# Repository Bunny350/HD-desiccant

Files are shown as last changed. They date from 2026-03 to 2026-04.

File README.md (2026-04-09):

# HD desiccant holder

*The best calibration model since everything else.*

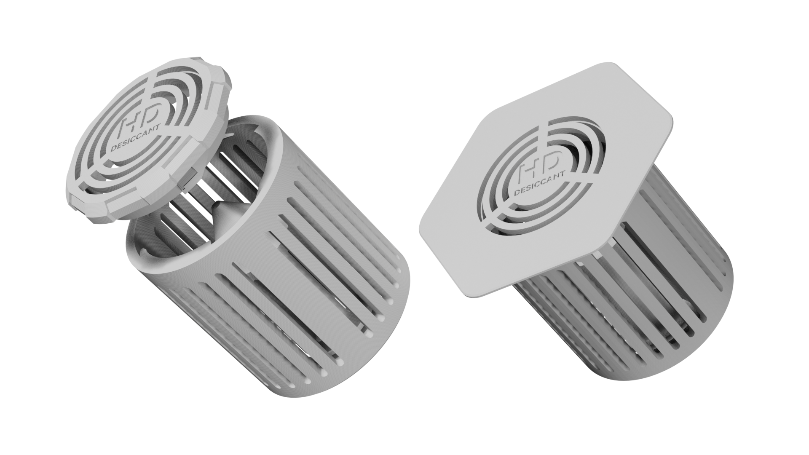
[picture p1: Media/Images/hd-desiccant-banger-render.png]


This desiccant holder / container is called HD desiccant holder because it holds any type of desiccant *in diameters that are within 3mm to 5mm*. It has 2mm wide grills that improves drying performance when being dried by normal filament dryers. Becuase of this, salvaging desiccant bags for this is not recommended as they contain pellets that are smaller than the holder's grill.

It is also a great printer / filament torture test as it tests every aspect of the printer's tolerances and mostly filament retraction.

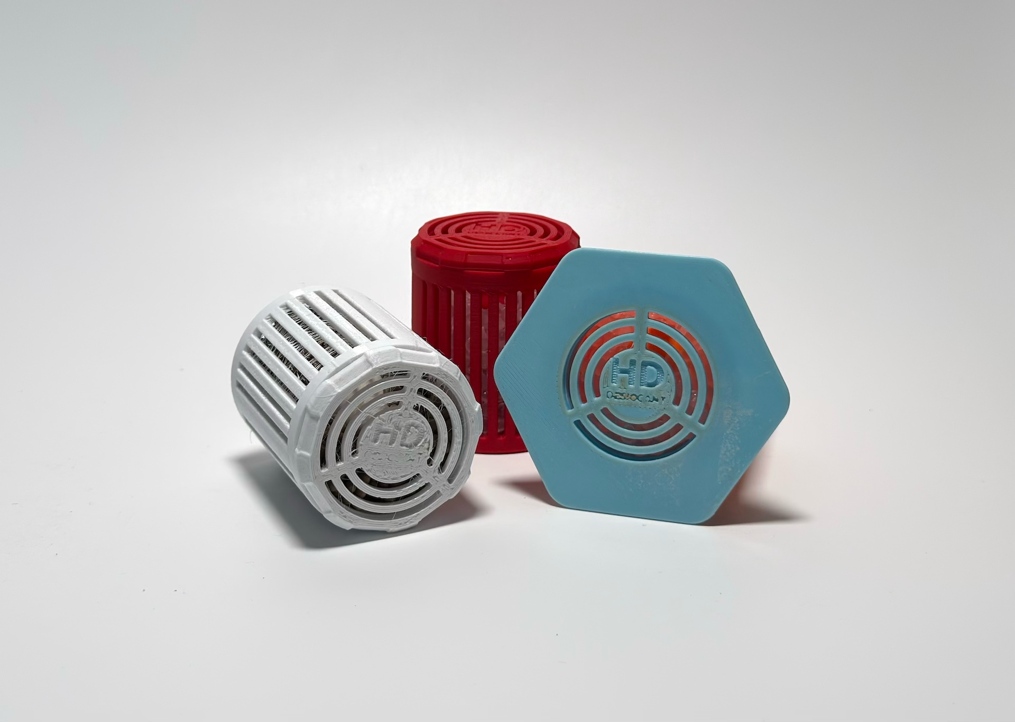
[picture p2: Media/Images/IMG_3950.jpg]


Since I don't like other desiccants for their strict tolerances **(after printing)** and the outcome of it's smaller pellet compatibility with poorer drying performance, I decided to make it myself. Heavily relied on thin extrude feature that introduced four years ago, and simple locking mechanism.

[Snappy sounds demo (Instagram)](https://www.instagram.com/reel/DVqocWHkwL2/)

## Recommended materials
* ABS
* ASA

* PET-G
    * May be minorly distortied by heat under high heat mode. However this does not affect the performance.
    
* PC
    * It requires excessive force to lock initially, at least V0.2378 and Bambu PC.
    
* FDM / FFF PA
    * It may lead to worse tolerances. It's probably one of the materials that are hard to tune.

* Just don't make it via PLA or PVB as these will have insanely obvious problems, unless it says it can tolerate high temperatures (something like Polymaker HT-PLA).

Any other materials, such as SLA photoplastics are also welcome, so we can torture more types of printers.

## Requirements
* The printer and the material must handle 0.2mm tolerances.
    * If the printer cannot handle 0.2mm tolerances, including but not limited to the lid not slotting into the bottom holder, then try drying the material first, before adjusting on the slicer- and printer-side.
    
* Easily-configurable parametric model requires either Fusion or online connection and MakerWorld.
* [Starter packs (drag-drop & YOLO print) is exclusive to MakerWorld.](https://makerworld.com/models/2565724-hd-desiccant-holder#profileId-2827543)

## Assembly



* Carefully fill the desiccant holder (desiccant_bottom_casing) using the desiccant of your choice.

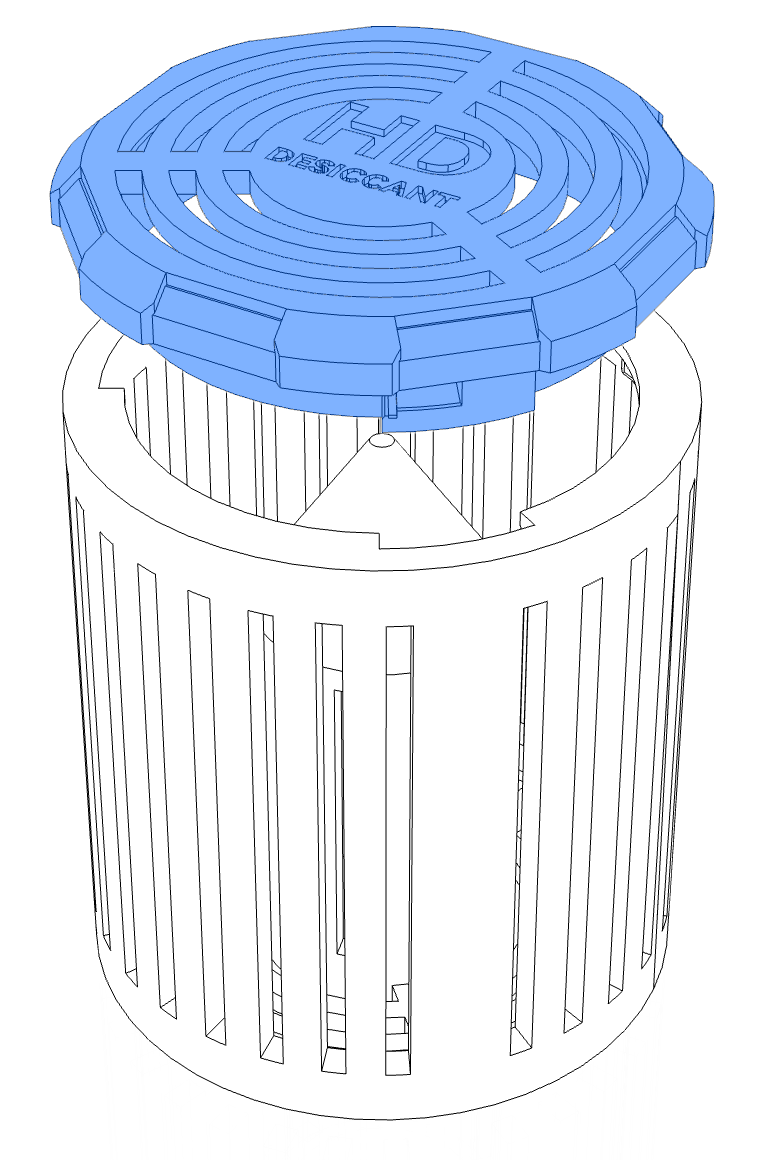
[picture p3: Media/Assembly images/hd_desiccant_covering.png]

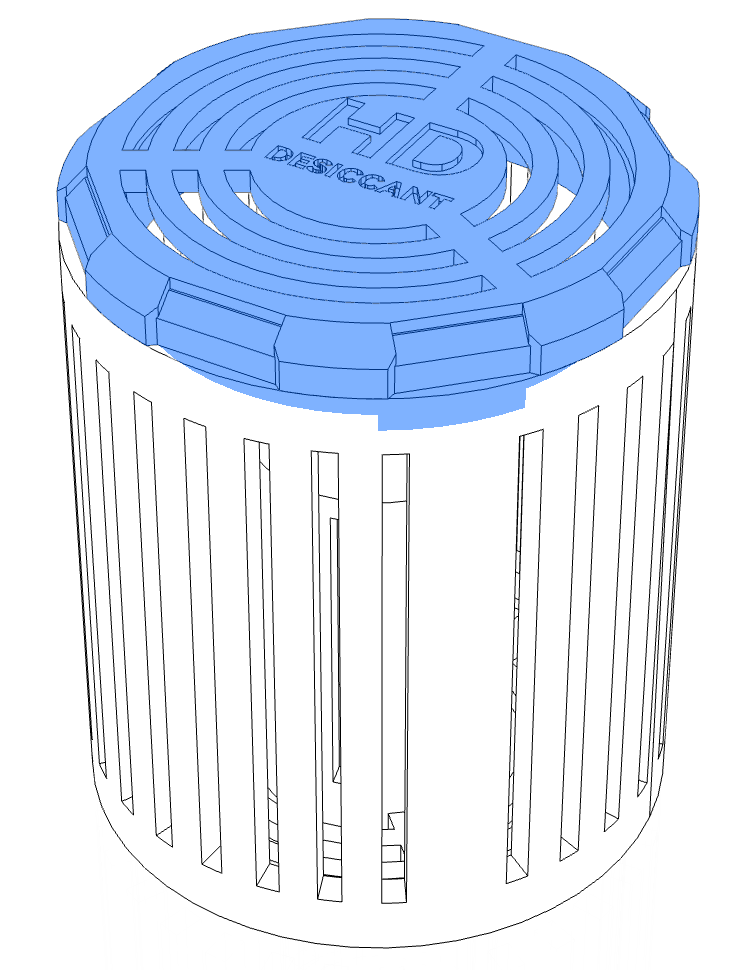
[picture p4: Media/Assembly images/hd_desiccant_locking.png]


*Note: these images are from the early prototype.*

* Close the desiccant holder with the lid (desiccant_top_lid). Turn the lid clockwise to lock it. It may make a click.

## Disassembly
If HD desiccant did not dry properly, or for whatever reason, you can easily disassemble it, as easy as assembling it.




*Note: these images are from the early prototype.*

* Turn the lid counter-clockwise, and then the lid will extend on its own. You can carefully pull the lid if it can't be extended on its own.
* The desiccant can be removed and rejuvenated without the holder.

## Drying
Desiccant in HD desiccant holder can be rejuvenated / dried within minimum setting of medium heat (around 60˚C) and 6 hours.

## Intense R&D
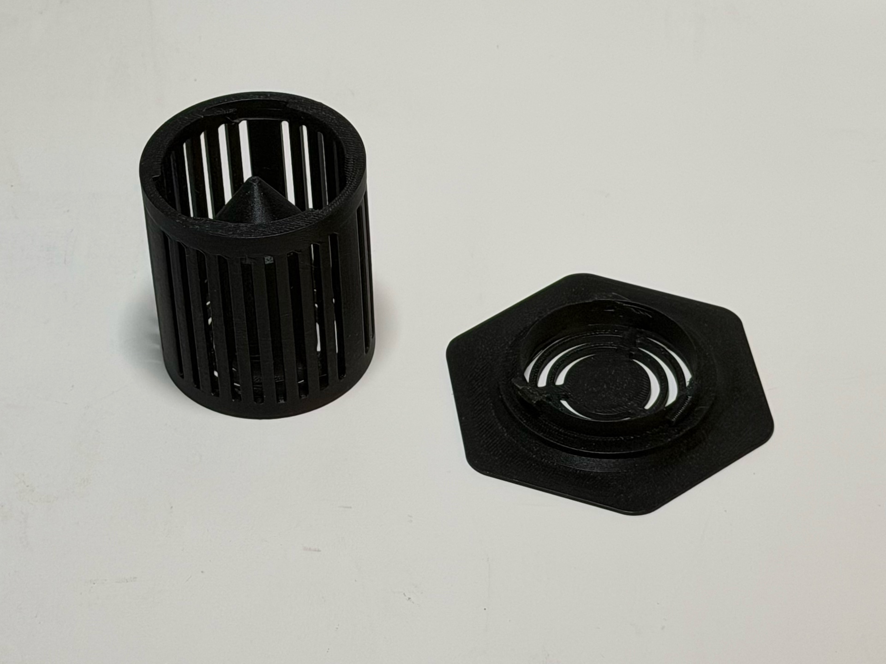
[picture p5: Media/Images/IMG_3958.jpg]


Before this model is being published to MakerWorld, I've managed to destroy multiples of these model just via hand and dropping. Apparently the design with sharp vertical corners are not suitable for typical FDM / FFF printing.

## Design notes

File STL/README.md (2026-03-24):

This file only contains the default configuration of HD desiccant. It has the height of 60mm. To change the desiccant container / holder's height, you may use its CAD file and adjust the height. You can also [visit it in MakerWorld](https://makerworld.com/models/2565724-hd-desiccant-holder#profileId-2827543) to adjust the height to your filament's thickness online.

You can choose either one with the normal top lid or the foolproof top lid with the hexagonal top brim.

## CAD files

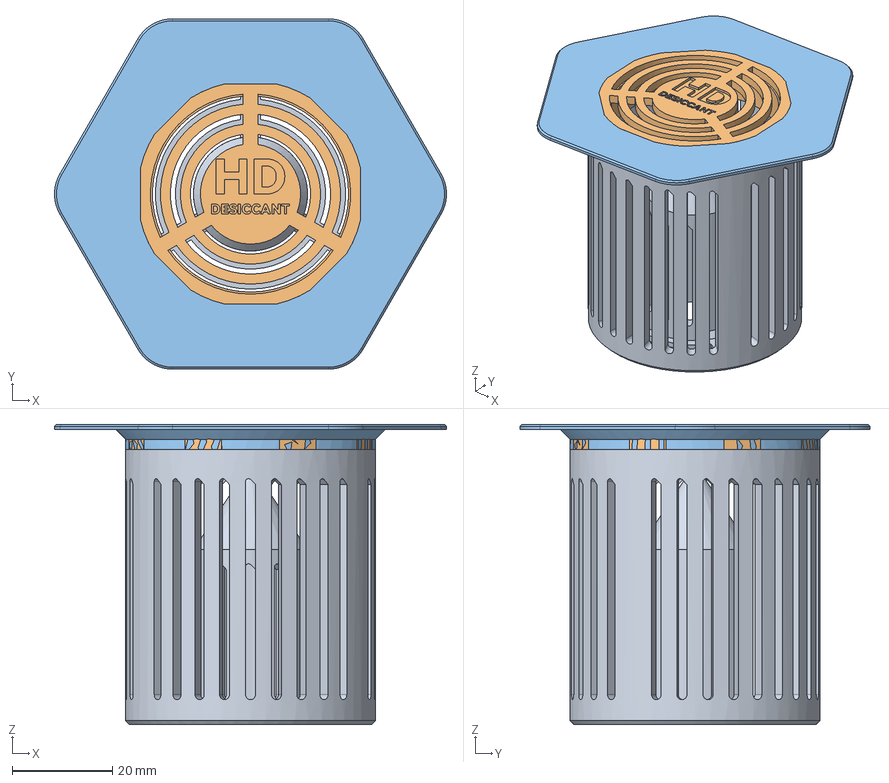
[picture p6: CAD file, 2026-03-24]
CAD/HD desiccant case.step
78.3 x 70.0 x 60.0 mm

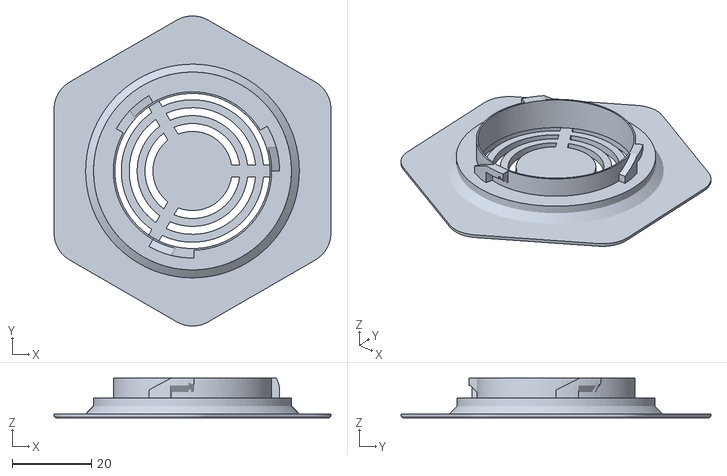
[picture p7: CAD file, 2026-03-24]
STL/desiccant_top_lid_foolproof.stl
70.0 x 78.3 x 10.0

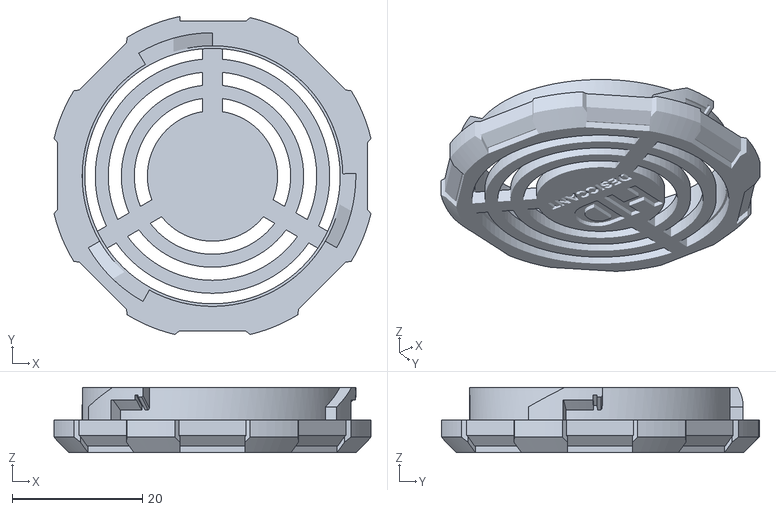
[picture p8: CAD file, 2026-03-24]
STL/desiccant_top_lid.stl
48.6 x 48.8 x 10.0

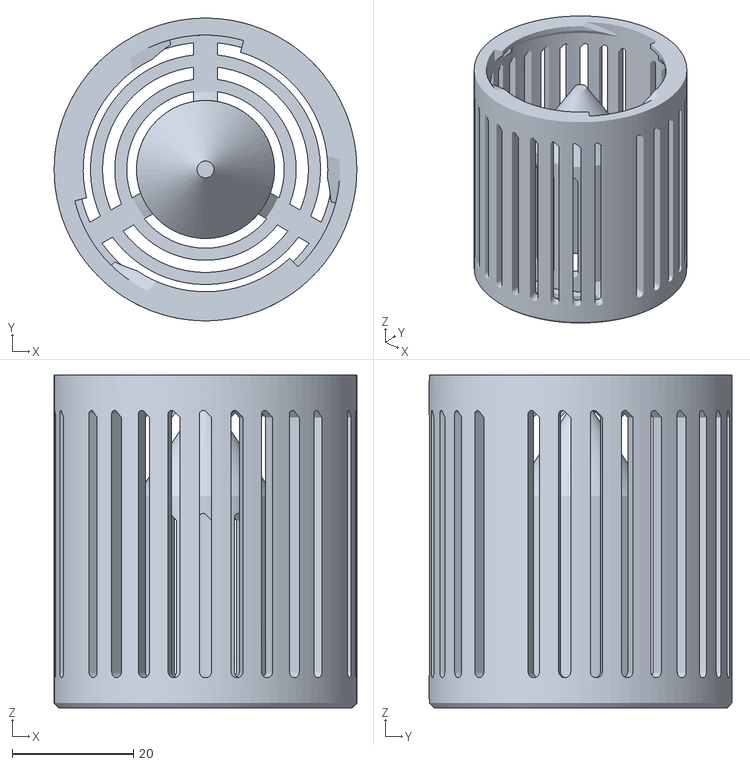
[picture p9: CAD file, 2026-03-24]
STL/desiccant_bottom_casing.stl
50.0 x 50.0 x 55.0

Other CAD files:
CAD/HD desiccant case.f3d

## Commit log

2026-03-05 Split HD desiccant to its own repo
    [HD desiccant case.f3d, HD desiccant case.step, desiccant_bottom_casing.stl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]
2026-03-24 Intense R&D
    This change enforces intense R&D with the budget of around $10 dollars just to make sure these things are more durable than ever. The old version did not have chamfered corners which FDM / FFF with p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
    [HD desiccant case.f3d, HD desiccant case.step, desiccant_bottom_casing.stl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]
2026-04-08 Update Readme document to include current materials
2026-05-07 Update LICENSE
    This is to reflect the current state of HD desiccant in MakerWorld, by (basically) allowing followers of Oitswilliam to sell HD desiccant on-request.
